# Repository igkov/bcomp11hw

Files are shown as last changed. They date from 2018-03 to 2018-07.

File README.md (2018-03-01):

# bcomp11hw

Hardware made in KiCad software. This project of BCOMP11 hardware. Description on http://igorkov.org/bcomp11 and http://igorkov.org/bcomp11v2 pages.

Actual Gerber files here:
* Version 2.0 - http://igorkov.org/zip/bcomp11v2-gerber.zip
* Version 2.3 - http://igorkov.org/zip/bcomp11v2-gerber23.zip

Other information:
* [Using CAN-PHY drivers](https://github.com/igkov/bcomp11hw/wiki/CAN-PHY-drivers)
* [Using universal I/O](https://github.com/igkov/bcomp11hw/wiki/Universal-IO)
* [NMPS schemes](https://github.com/igkov/bcomp11hw/wiki/NMPS-schemes)

## Scheme:



## Board:




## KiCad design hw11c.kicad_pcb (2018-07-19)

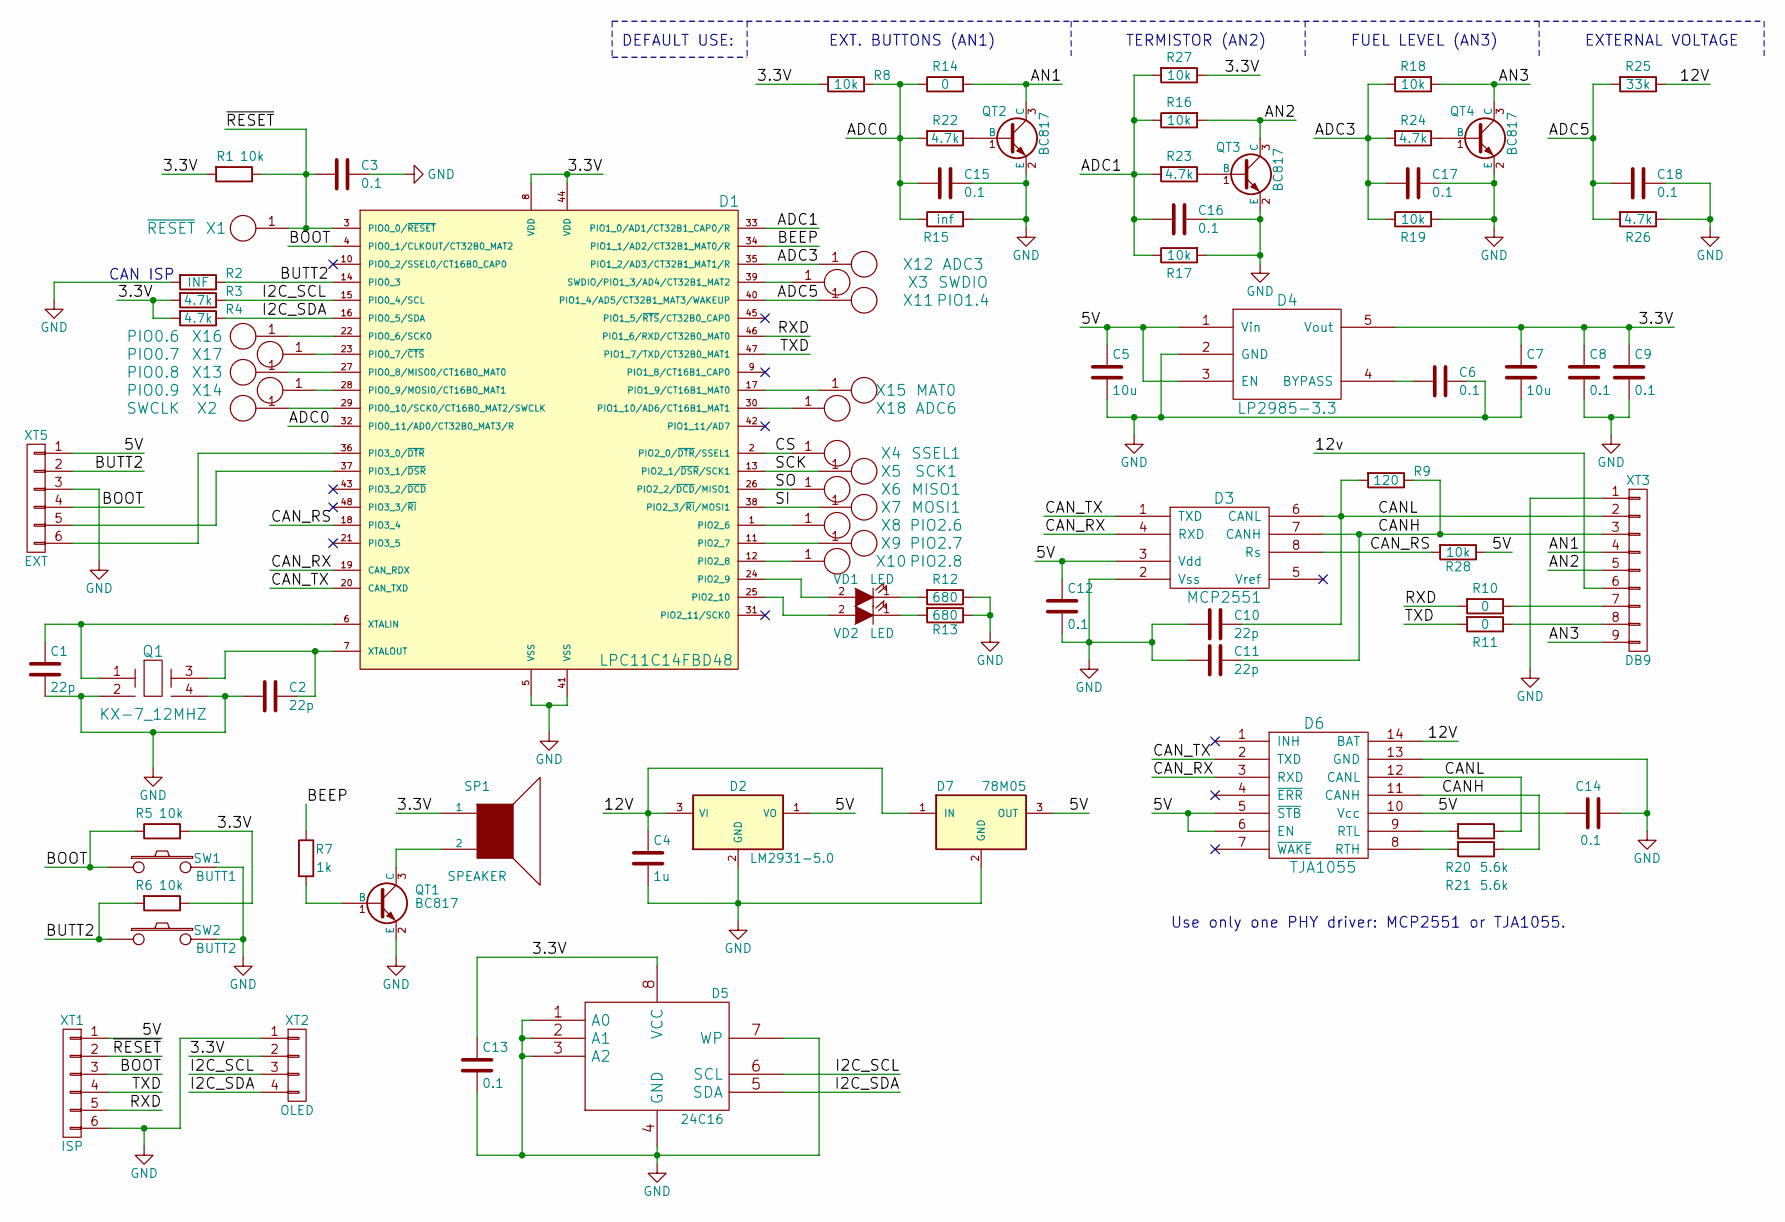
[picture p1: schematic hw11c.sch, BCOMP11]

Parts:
C1, C2, C10, C11: 22p; C_0603
C3, C6, C8, C9, C12, C13, C14, C15, C16, C17, C18: 0.1; C_0603
C4: 1u; C_1206
C5, C7: 10u; C_1206
D1: LPC11C14FBD48; LQFP-48_7x7mm_Pitch0.5mm
D2: LM2931-5.0; TO-92_Horizontal1_Inline_Narrow_Oval
D3: MCP2551; SOIC-8_3.9x4.9mm_Pitch1.27mm
D4: LP2985-3.3; SOT-23-5
D5: 24C16; SOIC-8_3.9x4.9mm_Pitch1.27mm
D6: TJA1055; SOIC-14_3.9x8.7mm_Pitch1.27mm
D7: 78M05; D-Pak_TO252AA
Q1: KX-7_12MHZ; KX-7
QT1, QT2, QT3, QT4: BC817; SOT-23
R1, R5, R6, R8, R16, R17, R18, R19, R27, R28: 10k; R_0603
R2: INF; R_0603
R3, R4, R22, R23, R24, R26: 4.7k; R_0603
R7: 1k; R_0603
R9: 120; R_0603
R10, R11, R14: 0; R_0603
R12, R13: 680; R_0603
R15: inf; R_0603
R20, R21: 5.6k; R_0603
R25: 33k; R_0603
SP1: SPEAKER; HC0901F
SW1: BUTT1; SW_SPST_FSMSM
SW2: BUTT2; SW_SPST_FSMSM
VD1, VD2: LED; LED-0603
X1: ~RESET; PAD
X2: SWCLK; PAD
X3: SWDIO; PAD
X4: SSEL1; PAD
X5: SCK1; PAD
X6: MISO1; PAD
X7: MOSI1; PAD
X8: PIO2.6; PAD
X9: PIO2.7; PAD
X10: PIO2.8; PAD
X11: PIO1.4; PAD
X12: ADC3; PAD
X13: PIO0.8; PAD
X14: PIO0.9; PAD
X15: MAT0; PAD
X16: PIO0.6; PAD
X17: PIO0.7; PAD
X18: ADC6; PAD
XT1: ISP; Pin_Header_Angled_1x06
XT2: OLED; OLED_I2C
XT3: DB9; DB9M_CI
XT5: EXT; Pin_Header_Straight_1x06

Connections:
/3.3V: C7.1, C8.1, C9.1, C13.1, D1.8 (VDD), D1.44 (VDD), D4.5 (Vout), D5.8 (VCC), R1.2, R3.2, R4.2, R5.2, R6.1, R8.2, R27.1, SP1.1, XT2.2
/5V: C5.1, C12.1, C14.1, D2.1 (VO), D3.3 (Vdd), D4.1 (Vin), D4.3 (EN), D6.5 (~STB), D6.6 (EN), D6.10 (Vcc), D7.3 (OUT), R28.1, XT1.1, XT5.1
/12V: C4.1, D2.3 (VI), D6.14 (BAT), D7.1 (IN), R25.1, XT3.6
/ADC0: C15.2, D1.32 (PIO0_11/AD0/CT32B0_MAT3/R), R8.1, R14.1, R15.1, R22.2
/ADC1: C16.2, D1.33 (PIO1_0/AD1/CT32B1_CAP0/R), R16.1, R17.1, R23.2, R27.2
/ADC3: C17.2, D1.35 (PIO1_2/AD3/CT32B1_MAT1/R), R18.1, R19.1, R24.2, X12.1
/ADC5: C18.2, D1.40 (PIO1_4/AD5/CT32B1_MAT3/WAKEUP), R25.2, R26.2, X11.1
/AN1: QT2.3 (C), R14.2, XT3.4
/AN2: QT3.3 (C), R16.2, XT3.5
/AN3: QT4.3 (C), R18.2, XT3.9
/BEEP: D1.34 (PIO1_1/AD2/CT32B1_MAT0/R), R7.1
/BOOT: D1.4 (PIO0_1/CLKOUT/CT32B0_MAT2), R5.1, SW1.1, XT1.3, XT5.4
/BUTT2: D1.14 (PIO0_3), R2.1, R6.2, SW2.1, XT5.2
/CANH: C11.1, D3.7 (CANH), D6.11 (CANH), R9.1, R21.1, XT3.3
/CANL: C10.1, D3.6 (CANL), D6.12 (CANL), R9.2, R20.1, XT3.2
/CAN_RS: D1.18 (PIO3_4), D3.8 (Rs), R28.2
/CAN_RX: D1.19 (CAN_RDX), D3.4 (RXD), D6.3 (RXD)
/CAN_TX: D1.20 (CAN_TXD), D3.1 (TXD), D6.2 (TXD)
/CS: D1.2 (PIO2_0/~DTR~/SSEL1), X4.1
/I2C_SCL: D1.15 (PIO0_4/SCL), D5.6 (SCL), R3.1, XT2.3
/I2C_SDA: D1.16 (PIO0_5/SDA), D5.5 (SDA), R4.1, XT2.4
/RXD: D1.46 (PIO1_6/RXD/CT32B0_MAT0), R10.2, XT1.5
/SCK: D1.13 (PIO2_1/~DSR~/SCK1), X5.1
/SI: D1.38 (PIO2_3/~RI~/MOSI1), X7.1
/SO: D1.26 (PIO2_2/~DCD~/MISO1), X6.1
/TXD: D1.47 (PIO1_7/TXD/CT32B0_MAT1), R11.2, XT1.4
/~RESET: C3.2, D1.3 (PIO0_0/~RESET~), R1.1, X1.1, XT1.2
GND: C1.2, C2.2, C3.1, C4.2, C5.2, C6.1, C7.2, C8.2, C9.2, C10.2, C11.2, C12.2, C13.2, C14.2, C15.1, C16.1, C17.1, C18.1, D1.5 (VSS), D1.41 (VSS), D2.2 (GND), D3.2 (Vss), D4.2 (GND), D5.1 (A0), D5.2 (A1), D5.3 (A2), D5.4 (GND), D5.7 (WP), D6.13 (GND), D7.2 (GND), Q1.2, Q1.4, QT1.2 (E), QT2.2 (E), QT3.2 (E), QT4.2 (E), R2.2, R12.1, R13.1, R15.2, R17.2, R19.2, R26.1, SW1.2, SW2.2, XT1.6, XT2.1, XT3.1, XT5.3
unnamed: C1.1, D1.6 (XTALIN), Q1.1
unnamed: C2.1, D1.7 (XTALOUT), Q1.3
unnamed: C6.2, D4.4 (BYPASS)
unnamed: D1.1 (PIO2_6), X8.1
unnamed: D1.11 (PIO2_7), X9.1
unnamed: D1.12 (PIO2_8), X10.1
unnamed: D1.17 (PIO1_9/CT16B1_MAT0), X15.1
unnamed: D1.22 (PIO0_6/SCK0), X16.1
unnamed: D1.23 (PIO0_7/~CTS~), X17.1
unnamed: D1.24 (PIO2_9), VD1.2 (A)
unnamed: D1.25 (PIO2_10), VD2.2 (A)
unnamed: D1.27 (PIO0_8/MISO0/CT16B0_MAT0), X13.1
unnamed: D1.28 (PIO0_9/MOSI0/CT16B0_MAT1), X14.1
unnamed: D1.29 (PIO0_10/SCK0/CT16B0_MAT2/SWCLK), X2.1
unnamed: D1.30 (PIO1_10/AD6/CT16B1_MAT1), X18.1
unnamed: D1.36 (PIO3_0/~DTR~), XT5.6
unnamed: D1.37 (PIO3_1/~DSR~), XT5.5
unnamed: D1.39 (SWDIO/PIO1_3/AD4/CT32B1_MAT2), X3.1
unnamed: D6.8 (RTH), R21.2
unnamed: D6.9 (RTL), R20.2
unnamed: QT1.1 (B), R7.2
unnamed: QT1.3 (C), SP1.2
unnamed: QT2.1 (B), R22.1
unnamed: QT3.1 (B), R23.1
unnamed: QT4.1 (B), R24.1
unnamed: R10.1, XT3.7
unnamed: R11.1, XT3.8
unnamed: R12.2, VD1.1 (K)
unnamed: R13.2, VD2.1 (K)

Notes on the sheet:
CAN ISP
Use only one PHY driver: MCP2551 or TJA1055.
EXT. BUTTONS (AN1)
TERMISTOR (AN2)
EXTERNAL VOLTAGE
FUEL LEVEL (AN3)
DEFAULT USE:

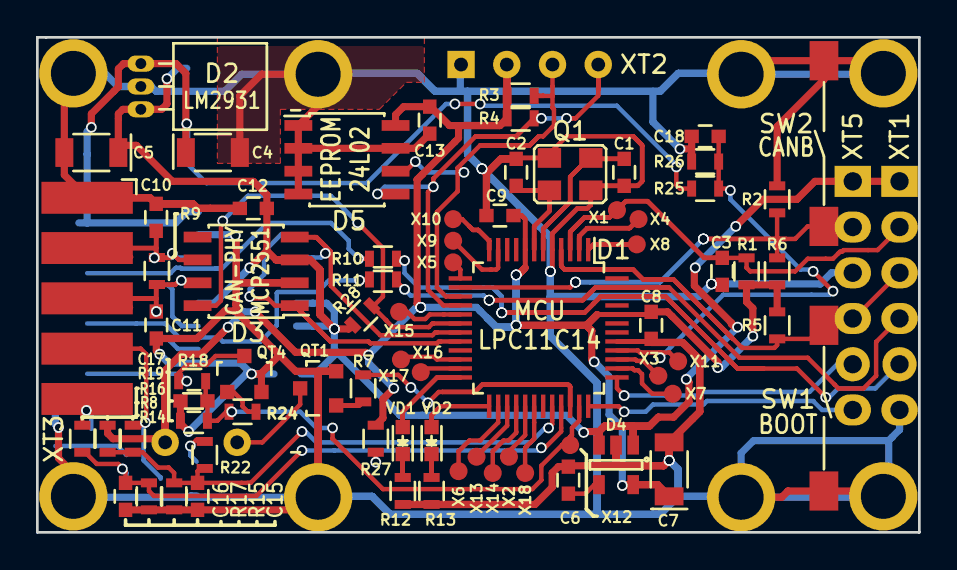
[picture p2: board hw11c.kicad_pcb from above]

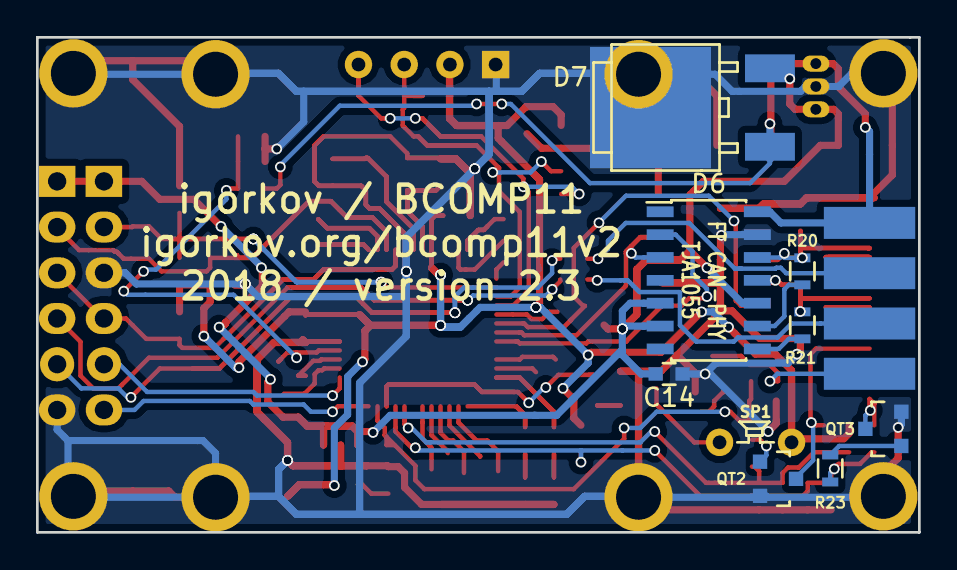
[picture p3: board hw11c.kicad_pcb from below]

Board: 2 copper layers, 49.0 x 27.5 mm, 85 parts (9 on the bottom side), 57 nets.

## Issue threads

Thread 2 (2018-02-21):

AN1, AN2, AN3 didn't have protect diodes

igkov, 2018-02-21:
AN1, AN2, AN3 didn't have protect diodes.
In currect realisaton this recomendations:
* In analog mode please use output resistor more 10kOm and resistive divide for input voltage 15V and more.
* In open-drain mode (relay use), please setup external protection diode.

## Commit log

2017-12-19 add all project files
    [hw11c.kicad_pcb, hw11c.sch]
2017-12-19 Add author information to board.
    [hw11c.kicad_pcb]
2017-12-21 Add termistor support in AN1 channel. Fix silk layer in board.
    [hw11c.kicad_pcb, hw11c.sch]
2017-12-22 Add AN3 channel on board.
    [hw11c.kicad_pcb]
2017-12-27 Add connector for external buttons.
    [hw11c.kicad_pcb, hw11c.sch]
2018-01-18 Replace XT4 to XT5, more pins in connector (P3.0 and P3.1 to extern).
    [hw11c.kicad_pcb, hw11c.sch]
2018-01-19 Add R10, R11 to RX and TX lines.
    [hw11c.kicad_pcb, hw11c.sch]
2018-01-22 Add X16/X17 pads. Fix buttons silk.
    [hw11c.kicad_pcb, hw11c.sch]
2018-02-02 Add holes at the edges of the board.
    [hw11c.kicad_pcb]
2018-02-02 New board size: 49x27.5mm.
    [hw11c.kicad_pcb]
2018-02-02 Sizes in brd vision.
    [hw11c.kicad_pcb]
2018-02-06 Add fault-tolerance CAN PHY: TJA1055. Version of board 2.1.
    [hw11c.kicad_pcb, hw11c.sch]
2018-02-06 Fix C5 position.
    [hw11c.kicad_pcb]
2018-02-16 Add open-drain outs (shared with analog input). Version 2.3.
    [hw11c.kicad_pcb, hw11c.sch]
2018-02-20 Fix silk layer. Add wiki links.
    [hw11c.kicad_pcb, hw11c.sch]
2018-03-01 Add links to Gerber-files.
2018-04-11 Fix SO-14 case for TJA-1055.
    [hw11c.kicad_pcb, hw11c.sch]
2018-04-11 Add LM78M05 to board. It used as alternate DC-DC for applications with current consumption more 100mA.
    [hw11c.kicad_pcb]
2018-06-09 Add resistive divider on ADC5 (AIN4) for system voltage measurement. Add reference voltage for AIN2. Add information on scheme.
    [hw11c.kicad_pcb, hw11c.sch]
2018-06-09 Clear TODO.md. Fix capasitors on scheme.
    [hw11c.sch]
2018-06-27 Add X18 pad.
    [hw11c.kicad_pcb, hw11c.sch]
2018-07-19 Add Rs signal for MCP2551. Pin connected to MCU pin 3.4.
    [hw11c.kicad_pcb, hw11c.sch]
